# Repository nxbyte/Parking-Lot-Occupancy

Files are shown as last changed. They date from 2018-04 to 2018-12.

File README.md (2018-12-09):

# Parking Lot Occupancy

Undergraduate Senior Project focusing on detecting vehicle occupancy for parking lots



## Abstract

As The College of New Jersey increases its student and faculty size, there is an ever increasing need to manage its growth appropriately. One area in particular need of attention is parking on campus. Currently, many commuting facility, staff, and students attempt to find available parking spaces by driving around to different parking lots and guessing where parking spaces may be available.

The **Parking Lot Availability and Traffic Prediction System** provides commuters with information about the availability of free parking spaces, which will not only alleviate traffic congestion but also increase coordination for commuters. This system is made up of three components: detection nodes to detect vehicles entering and exiting parking lots, a base station that will host a wireless network to collect traffic data from each detection node, and a web server to provide current parking space availability at a glance. Each detection unit contains: sensors, wireless radio, and custom solar charging circuit for renewable outdoor operation. The base station contains a microcomputer and a wireless radio to communicate with each detection unit. All traffic data is securely stored and displayed on an Amazon web server which is accessible to TCNJ commuters. The final product allows commuters to view the status of open spaces and make The College of New Jersey a better and more coordinated campus. This system can be adapted to any environment with a gate and/or a road.

## Overall Architecture

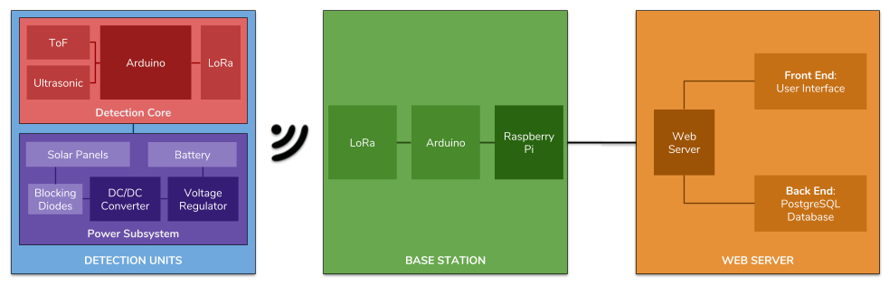
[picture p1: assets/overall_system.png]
Overall Architecture


## Credits

**Core Team**

- Warren Seto (Computer Engineer, Class of 2018)
- Nikita Eisenhauer (Electrical Engineer, Class of 2018)
- Stephanie Fournier (Electrical Engineer, Class of 2018)
- Matthew Cook (Computer Engineer, Class of 2018)
- Dr. Larry Pearlstein (Advisor)

**With help from...**

- Michael Steeil (TCNJ Engineering Laboratory Technician)
- Grant Cignarella (Mechanical Engineer, Class of 2020)
- Joshua Acker (Mechanical Engineer, Class of 2018)
- Lindsey Abramson (Computer Science, Class of 2018)
- Elisa Idrobo (Computer Science, Class of 2018)
- Philip Franco (Electrical Engineer, Class of 2019)
- Justin Cheng (Mechanical Engineer, Class of 2017)

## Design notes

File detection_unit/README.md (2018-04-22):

# Detection Unit

The Detection Unit is a device that is placed at the entrance and exit to each of the parking lots that are to be monitored with the system. 

**Each Detection Unit includes the following:**

- Microcontroller and sensor package, called Detection Unit Core
- Power subsystem, which includes solar panels, battery and associated electronics
- A 3D printed enclosure

## Microcontrollers

##### Adafruit Feather 32u4
The Adafruit Feather 32u4 microcontroller is an Arduino based microcontroller. The sensor has an onboard LoRa radio. The microcontroller uses SPI to communicate with the LoRa radio. The 32u4 also features an I2C interface, many different pins for GPIO, Digital IO, Analog IO, an antenna pin, a power cable connector for connecting to a power source, and a micro-USB port for power and programming.

##### Custom Arduino Microcontroller
The idea to make a PCB of an Arduino Uno was proposed to save cost, have experience with PCB CAD, and conserve space in the enclosure. The program used to design the PCB is Eagle CAD due to its compatibility with printing companies and its popularity allowing the user to have access to many tutorials. In order to build the Arduino, it is necessary to know the components used in an Arduino that will be needed in the PCB and all the hardware that will be needing the Arduino.

## Sensors & Peripherals

##### Ultrasonic Sensor
The Maxbotix LV-MaxSonar-EZ1 Ultrasonic Range Finder is an ultrasonic sensor that uses Analog output to communicate with a host microcontroller. Ultrasonic sensors emit ultrasonic pulses that can bounce off objects and calculate the distance based on the amount of time sound takes to reach the sensor. The sensor has a theoretical detection range of 6.45 meters from is initial position. Each Detection Unit Core uses one of these sensors positioned towards the curb of a street. The Ultrasonic Range Finder is used to detect whether a vehicle is passing by the Detection Unit.

##### Time of Flight Infrared Sensor
The Adafruit VL53L0X Time of Flight Distance Sensor is a LIDAR sensor that uses I2C to communicate with a host microcontroller. LIDAR is a technology that uses laser light pulses to determine the distance between the sensor and the object in front of the sensor. The sensor has a theoretical detection range of up to one meter from is initial position. Each Detection Unit Core uses one of these sensors positioned upwards the gate above the Detection Unit. The Time of Flight Sensor is used to detect the position of the gate and verify that an authorized vehicle has passed through the entrance of a parking lot. 

## Detection Algorithm

To accurately detect a vehicle, the group wanted to use all current infrastructure already setup in the parking lot such as the limited roadways and established gate units at the entrance. After researching into possible sensors to sense the state of the entrance, the group chose two types of sensors to go into each Detection Unit. The first sensor, the Maxbotix LV-MaxSonar-EZ1 Ultrasonic Range Finder, is tasked with detecting whether an entity (vehicle or animal) enters the parking lot. The Ultrasonic Range Finder, has a theoretical detection range of 6.45 meters (645 cm). After testing the sensor in the field, the sensor actually had a detection range of 4.5 meters (450 cm) which still satisfied the group’s detection requirements of detecting an entity on a 325 cm roadway. The first sensor, the Adafruit VL53L0X Time of Flight Distance Sensor, is tasked with detecting whether a given object entering the lot is authorized to enter by determining the position of the gate unit. The group determined that an authorized vehicle would make the gate rise which would be detected by the Distance sensor. The Time of Flight Distance Sensor, has a theoretical detection range of two meters (200 cm). After testing the sensor in the field, the sensor was tuned and scaled to sense a meter which satisfied the group’s detection requirements of detecting the gate at rest which was 92 cm above the island. Before any hardware was used for detection, the group calibrated each sensor with the gate and roadway in the entrance of the parking lot.

Through testing with driving vehicles through the entrance of the parking lot multiple times, the group determined that the Detection Unit will count an object as a valid vehicle entering the parking lot when both sensors reach a certain state. When the entrance to a parking lot has no vehicles entering, the ultrasonic sensor would read the maximum range value (approximately 450 cm) and the infrared distance sensor would read a constant 92 cm. When a vehicle enters the parking lot, the ultrasonic sensor would detect a drop in distance over a period of 4 seconds which will cause the infrared distance sensor to begin tracking the position of the gate unit for 5 seconds. Since the gate unit is near the maximum range of the distance sensor, when the gate unit opens the distance sensor will output the maximum range (2 meters). When both the ultrasonic sensor reads a drop in distance and the infrared distance sensor outputs its maximum range value, a vehicle is counted and sent to a centralized server. After performing various experiments with 100 entering vehicles, the group found that this method allowed the Detection Unit to detect 98% of authorized vehicles entering the parking lot. 

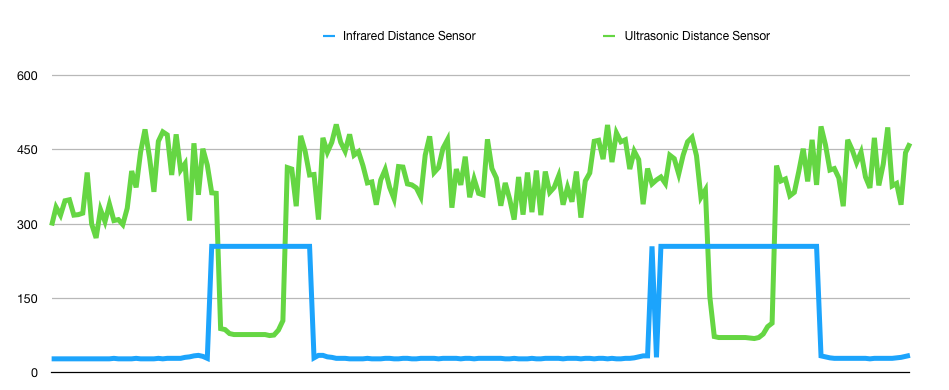
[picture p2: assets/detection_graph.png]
Sensor Graph


## Power Subsystem

Large pre-existing parking lots offer limited external power connections AC power, and the addition of such connections would be costly. Laying wires would present safety concerns for drivers and cumbersome gantry supports to allow overhead connections would be impractical. To minimize the burden of deployment of detection units in a large number of parking lots at TCNJ, we provide autonomous power to each detection unit, without requiring a connection to an AC power line. Stable, continuous power is required for proper operation of the detection unit subsystems and components.  A compact and standalone solar system was developed for use with each unit, allowing for greater freedom of placement and minimal external wiring as compared to alternative energy sources such as wind. Solar also provided scalable power as opposed to a much more restricted low power energy harvesting system. Charge storage in the event of poor solar insolation due to bad weather and for overnight detection unit power demands was accounted for with a LiPo battery charging circuit. LiPo batteries being available in significantly smaller packages than their Lithium-Ion battery counterparts allowed for the design of a smaller waterproof enclosure. To ensure battery longevity and safety, circuit elements to provide overcurrent and voltage regulation protection were included. Additionally, a DC/DC boost converter was necessary to account for the unique power demands and losses of the individual detection unit components. 

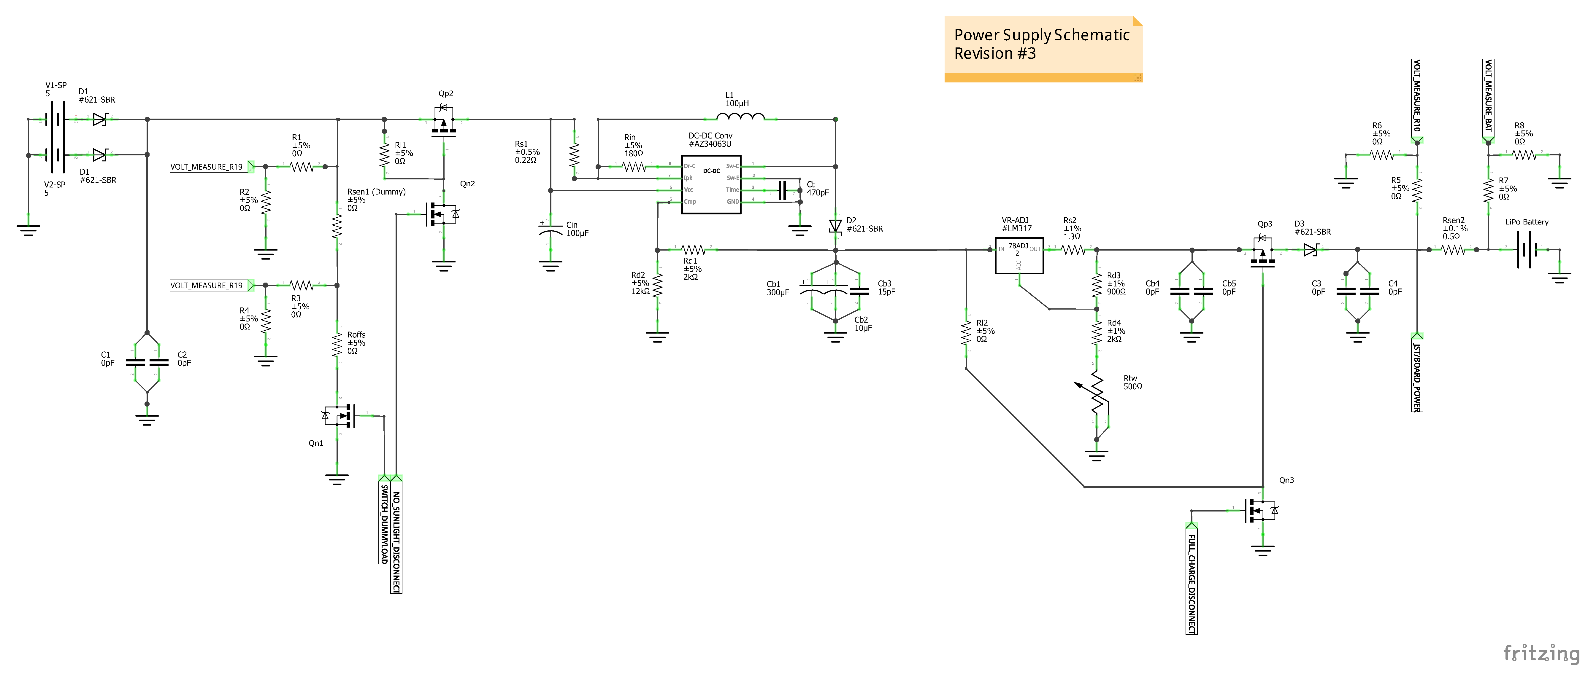
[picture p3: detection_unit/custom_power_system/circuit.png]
Overall Architecture


## Enclosure

A major component of this project is the detection system that relays the information of the sensors to the base station and the power system that powers the detection system using a solar panel. In order to keep all the components of each system in place and intact, an enclosure for the detection unit was proposed. Along with verifying that the hardware of these systems would be secure from the environment, it acts as a mount for the sensors to detect the moving vehicles. The design of the enclosure was based on the needs previously mentioned above and due to trial error, there are five versions of the first prototype all designed using CAD in Autodesk Fusion 360.

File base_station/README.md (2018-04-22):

# Base Station

The base station is a device that will receive payloads from the detection units and transmit its state to an Amazon cloud server. In order to receive payloads from the detection units, the base station will host a long distance wireless network with a designed range of one mile in diameter. Once a payload is received from a detection unit, the base station will decrypt the incoming transmission and parse the payload for metadata related to the detection unit that sent the data. Detection Unit payloads consists of: the client serial identification code and the payload to transmit to the Amazon cloud server. After decryption and parsing the payload, the base station will transmit the payload to the Amazon cloud server for further analysis. 

## Hardware

The hardware for the base station was chosen based on power usage, wireless performance, processing performance, and cost. The wireless network uses SemTech’s wireless LoRa (Long Range) technology. LoRa provides a greater wireless range than Wi-Fi, Bluetooth, or ZigBee while being more cost efficient than using a cellular network service as it does not incur wireless usage fees during its operation. The hosted wireless LoRa network will use the open 915 MHz ISM Band for ITU “Americas” which is free to use for industrial and scientific purposes. This allows the group to use publicly available spectrum space to transmit data on campus. The base station will have an antenna which is connected to an Arduino compatible Adafruit Feather that has the LoRa radio hardware for incoming transmissions. The Adafruit Feather connects to a 900 MHz dipole antenna to increase the range of the wireless network to encompass the TCNJ campus. The Adafruit Feather is then connected to a microcomputer called the Raspberry Pi to perform the routing and multiplexing needed to communicate with the Amazon cloud server. The Raspberry Pi features: USB to connect the Adafruit Feather to the microcomputer, 100-BaseT ethernet, and SD Card storage to hold the firmware that can be updated from a software update hosted from GitHub and the Amazon cloud server. The Raspberry Pi will be connected to the campus internet via CAT 6 Ethernet and a micro-USB 2 cable to power both the Raspberry Pi and the Adafruit Feather.

## Software

Based on the base station’s hardware, its software will need to provide routing functionality in between different system components. The Adafruit Feather with the LoRa radio will contain software will not only broadcast a LoRa wireless network using the 915 MHz spectrum space but also receive data that are transmitted from each detection unit. The Arduino software will be linked against the Arduino standard library and the RadioHead LoRa wireless library. The software on the Raspberry Pi will include a stripped-down Linux Debian operating system, the nodeJS server environment, and controller code to accept serial data from the Adafruit Feather and multiplex the payload to the Amazon cloud server. On boot, the Raspberry Pi will attempt to search for and update itself with the latest software from GitHub. Then the nodeJS server will then route the received payload.

## Enclosure

The team also designed an enclosure to house the components that will be needed for the base station. The base station will be located within the interior of the building and does not need to be weatherproof. This allowed the design to be more flexible in terms of its open holes and places where there needs to be sealed. To house the components, there is a top and bottom which allows the components to be mounted on the bottom and a twist on lid to completely enclosure the components. Holes and grooves on the bottom will allow for cable routing for power, ethernet and USB.

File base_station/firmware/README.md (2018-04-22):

# R1
Repository for Internal Wireless Router assets

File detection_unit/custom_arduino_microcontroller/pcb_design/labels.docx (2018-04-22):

LoRa - 9 hole header

9 - RST

8 - CS

7 - MOSI

6 - MISO

5 - SCK

4 - G0

3 - EN

2 - GND

1 - VIN

LIDAR - 14 hole header, each column representing one sensor

13, 14 - Vin

11, 12 - 2v8

9, 10 - GND

7, 8 - GPIO

5, 6 - SHDN

3, 4 - SCL

1, 2 - SDA

ATMEGA328P-PU - 30 hole header (didn’t have a 28 header). Each column representing one side of the chip.

27 - PC6 28 - PC5

25 - PD0 26 - PC4

23 - PD1 24 - PC3

21 - PD2 22 - PC2

19 - PD3 20 - PC1

17 - PD4 18 - PC0

15 - VCC 16 - GND

13 - GND 14 - AREF

11 - PB6 12 - AVCC

9 - PB7 10 - PB5

7 - PD5 8 - PB4

5 - PD6 6 - PB3

3 - PD7 4 - PB2

1 - PB0 2 - PB1

FTDI

6 - PC6 (1)

5 - PD1 (3)

4 - PD0 (2)

3 - VCC (7)

2 -

1 - GND (8)

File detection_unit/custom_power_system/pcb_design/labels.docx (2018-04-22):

3 pin header:

1 - “dummy load switch”

2 - “primary no sunlight”

3 - “secondary no sunlight”

4 pin header:

1 - “dummy load top”

2 - “dummy load bottom”

3 - “battery left”

4 - “battery right”

7 pin header:

1 - “solar panel 1”

2 - “solar panel 2”

3 - Battery

4 - Load

5 - GND

6 - GND

7 - GND

Q1 - leftmost diode on schematic

Q2 - middle diode on schematic

Q3 - rightmost diode on schematic

JP1: diode after solar panel test point

JP2: between resistors near Q5

JP3: pinout 6 on DC/DC

JP4: pinout 1/ between diode and inductor

JP5: VIN regulator

JP6: VOUT regulator

JP7: Potentiometer

JP8: battery

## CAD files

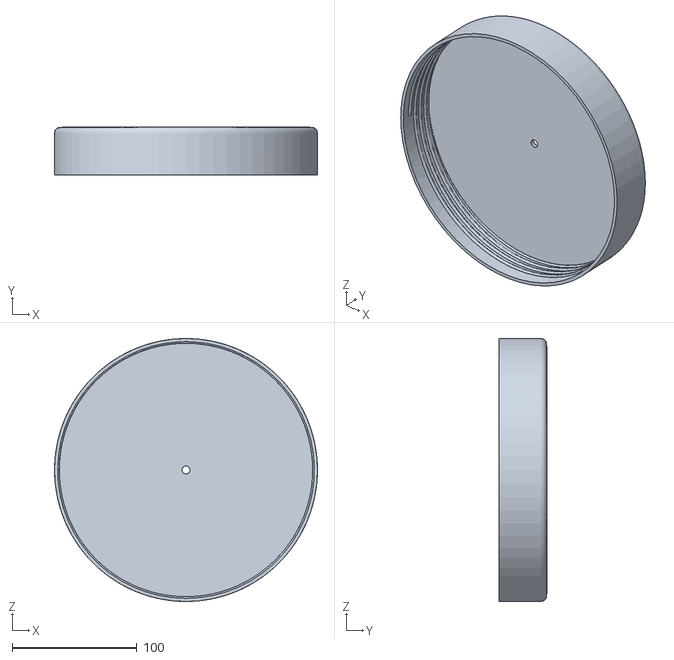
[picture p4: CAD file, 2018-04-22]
base_station/enclosure/lid.stl
210.8 x 38.1 x 210.8

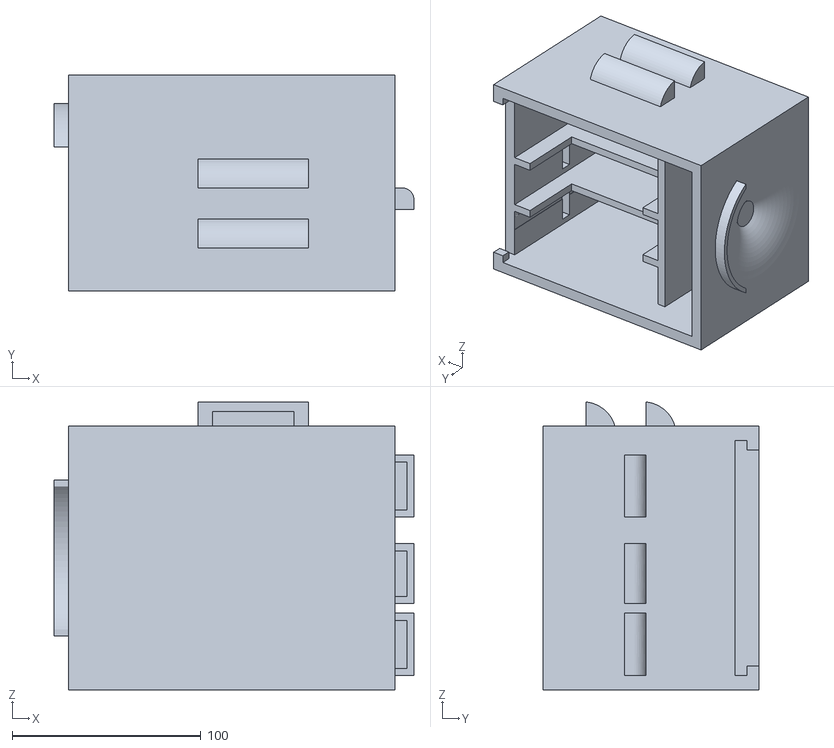
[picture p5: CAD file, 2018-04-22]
detection_unit/enclosure/body.stl
190.5 x 114.3 x 152.4

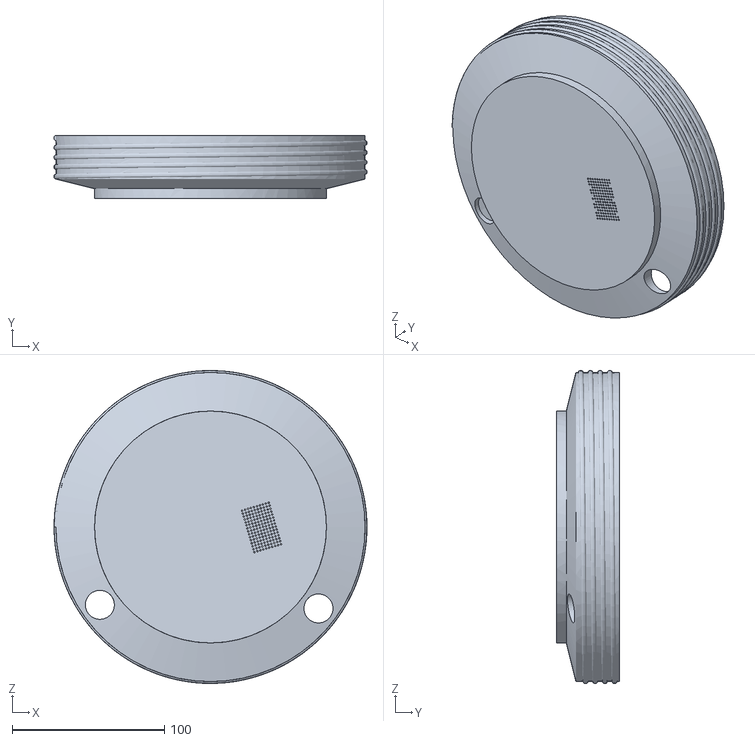
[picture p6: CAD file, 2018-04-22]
base_station/enclosure/body.stl
205.7 x 41.3 x 205.7

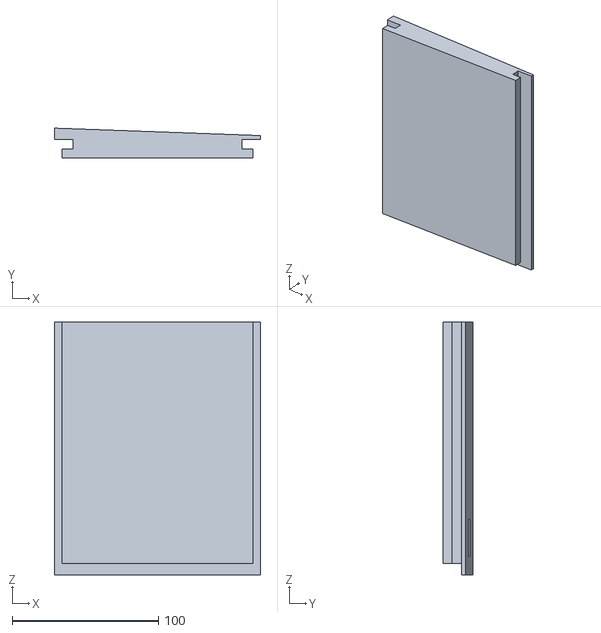
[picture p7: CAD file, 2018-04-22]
detection_unit/enclosure/lid.stl
141.0 x 20.3 x 172.7

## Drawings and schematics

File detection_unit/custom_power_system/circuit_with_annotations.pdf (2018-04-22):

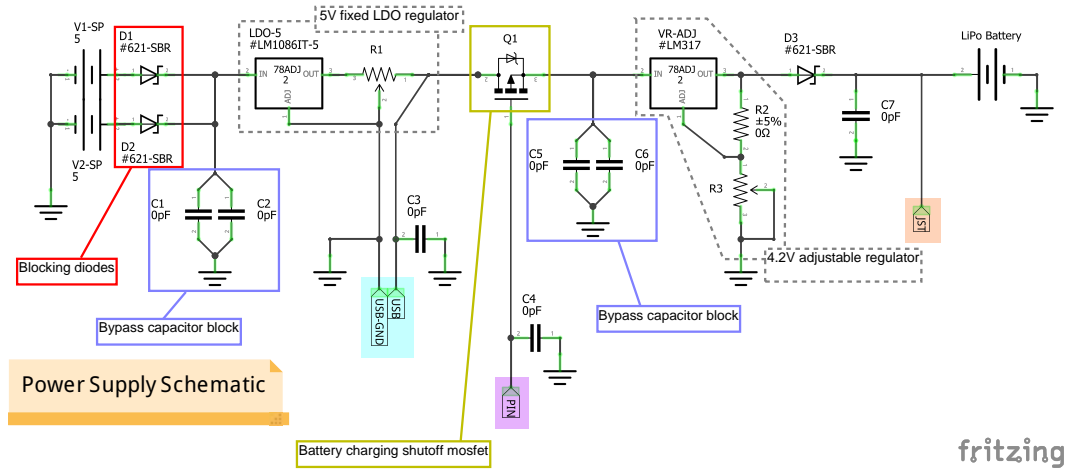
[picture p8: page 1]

Power Supply Schematic

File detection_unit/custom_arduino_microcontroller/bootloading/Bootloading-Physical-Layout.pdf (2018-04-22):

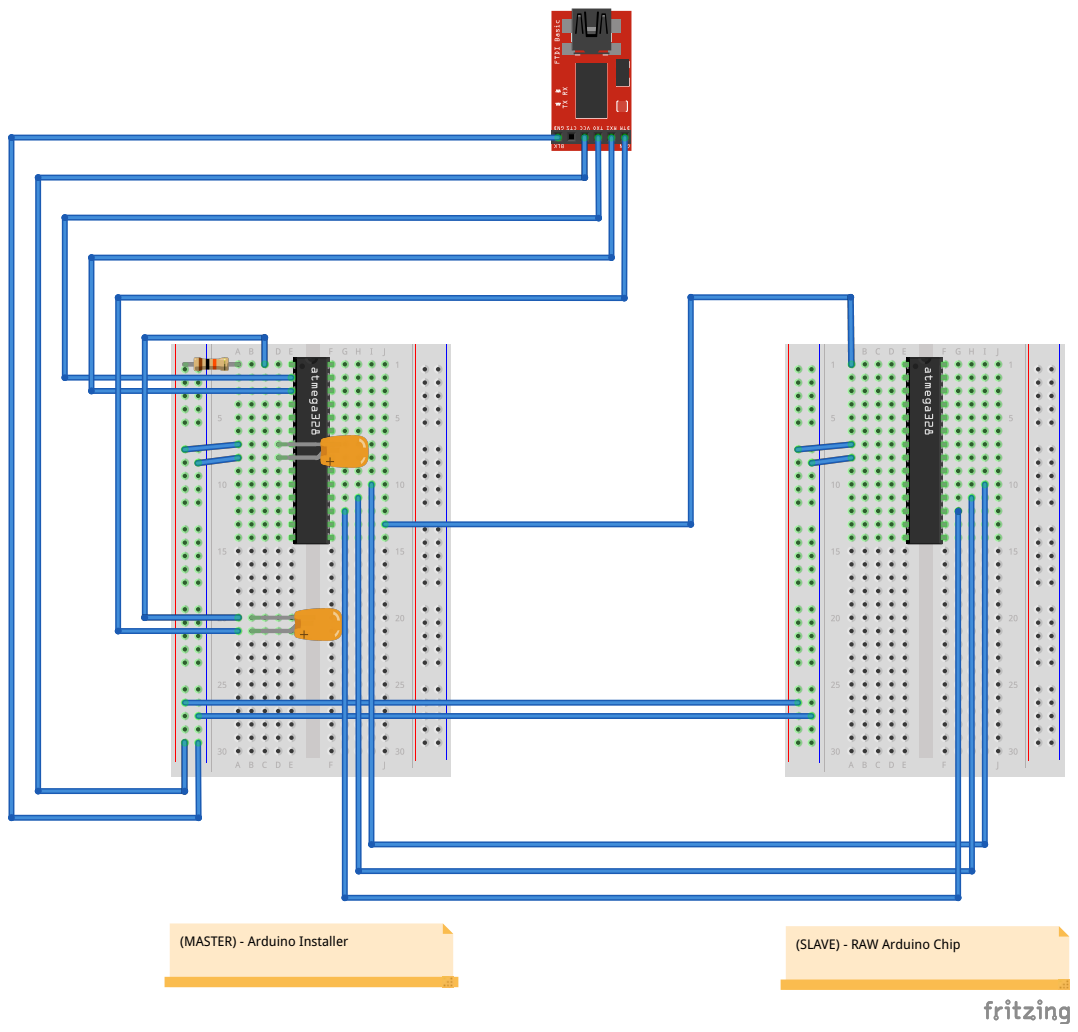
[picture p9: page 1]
(MASTER) - Arduino Installer; (SLAVE) - RAW Arduino Chip

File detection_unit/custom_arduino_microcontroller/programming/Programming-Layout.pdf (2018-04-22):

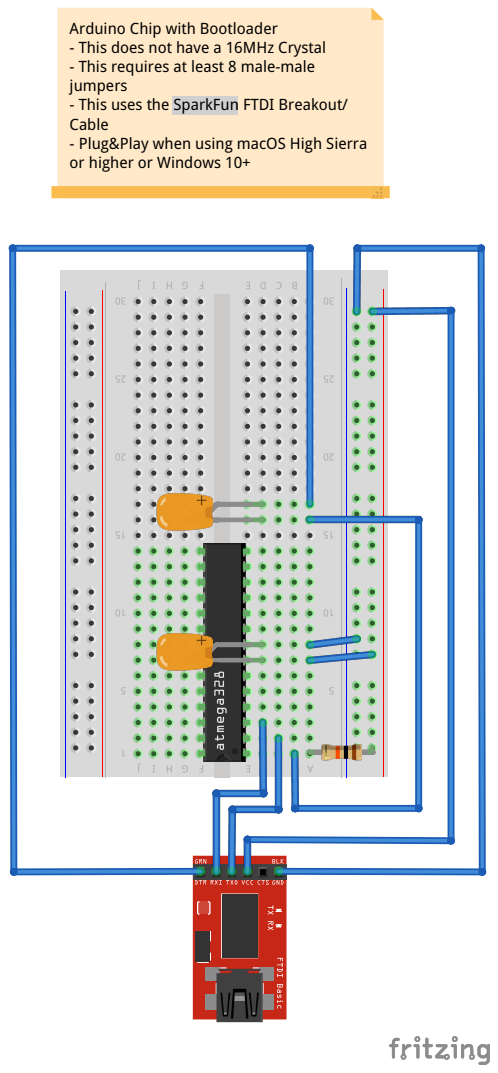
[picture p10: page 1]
the SparkFun

Arduino Chip with Bootloader
- This does not have a 16MHz Crystal
- This requires at least 8 male-male
jumpers

Cable
- Plug&Play when using macOS High Sierra
or higher or Windows 10+

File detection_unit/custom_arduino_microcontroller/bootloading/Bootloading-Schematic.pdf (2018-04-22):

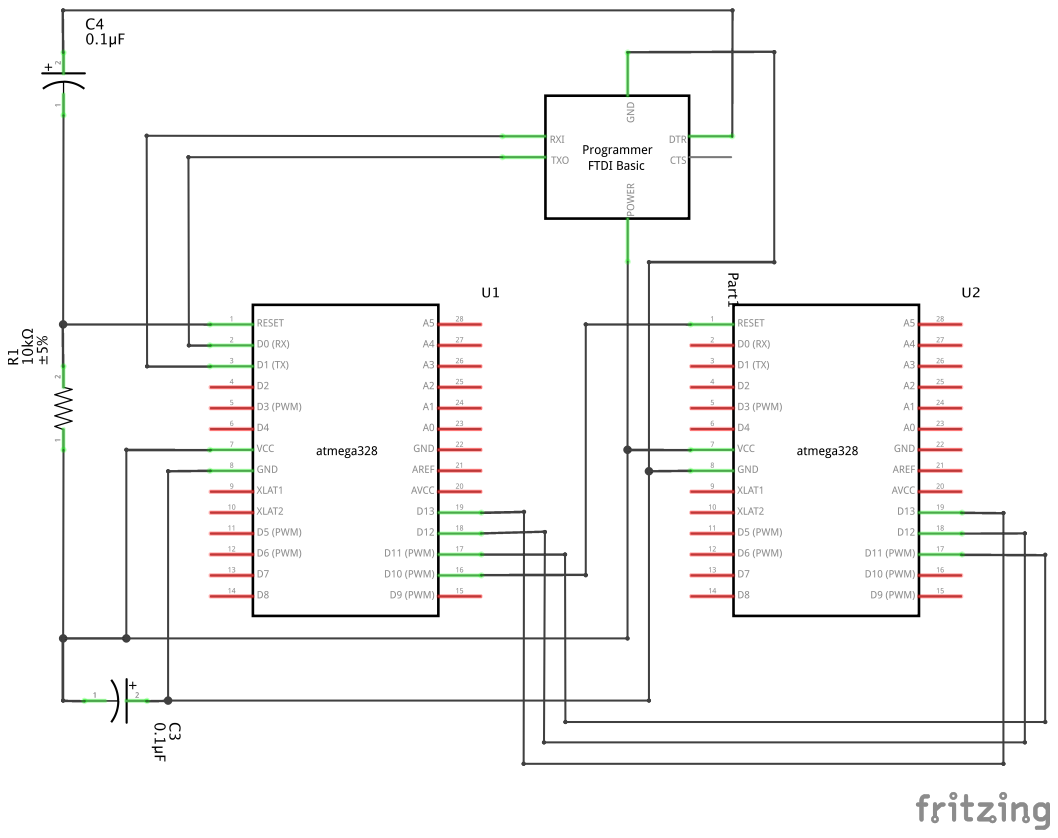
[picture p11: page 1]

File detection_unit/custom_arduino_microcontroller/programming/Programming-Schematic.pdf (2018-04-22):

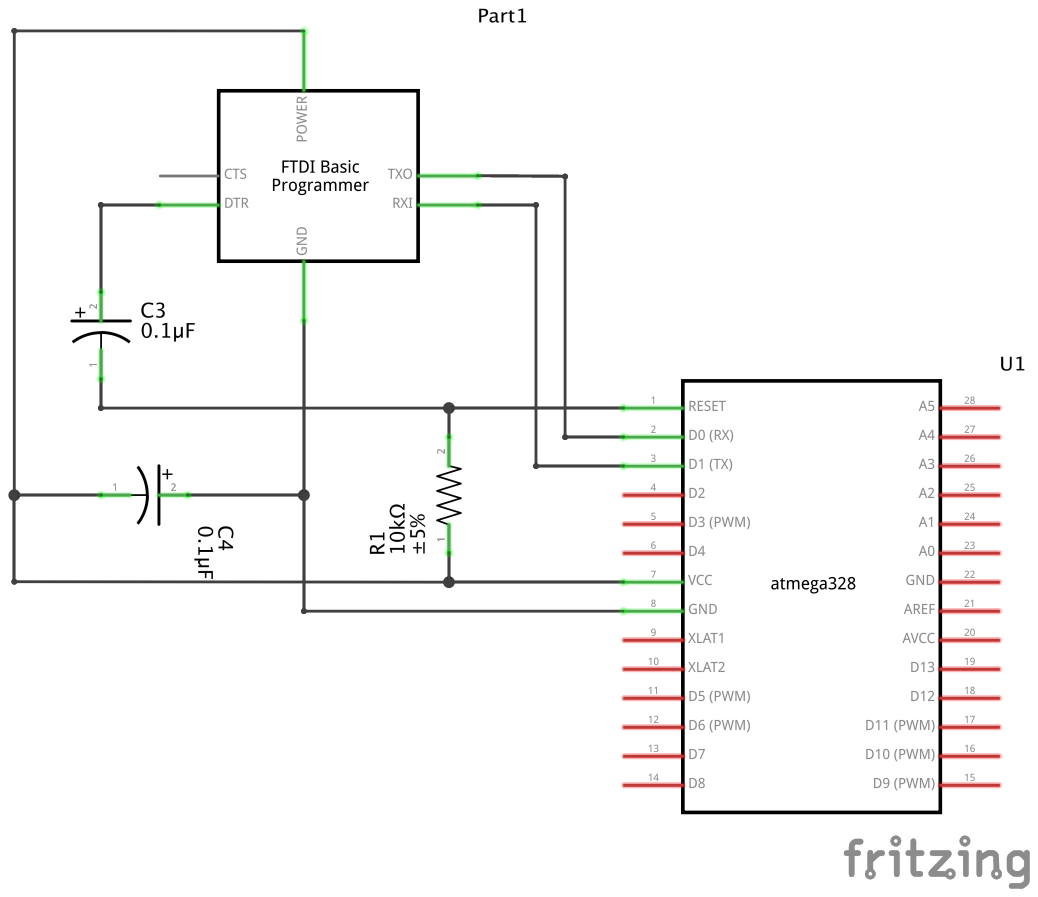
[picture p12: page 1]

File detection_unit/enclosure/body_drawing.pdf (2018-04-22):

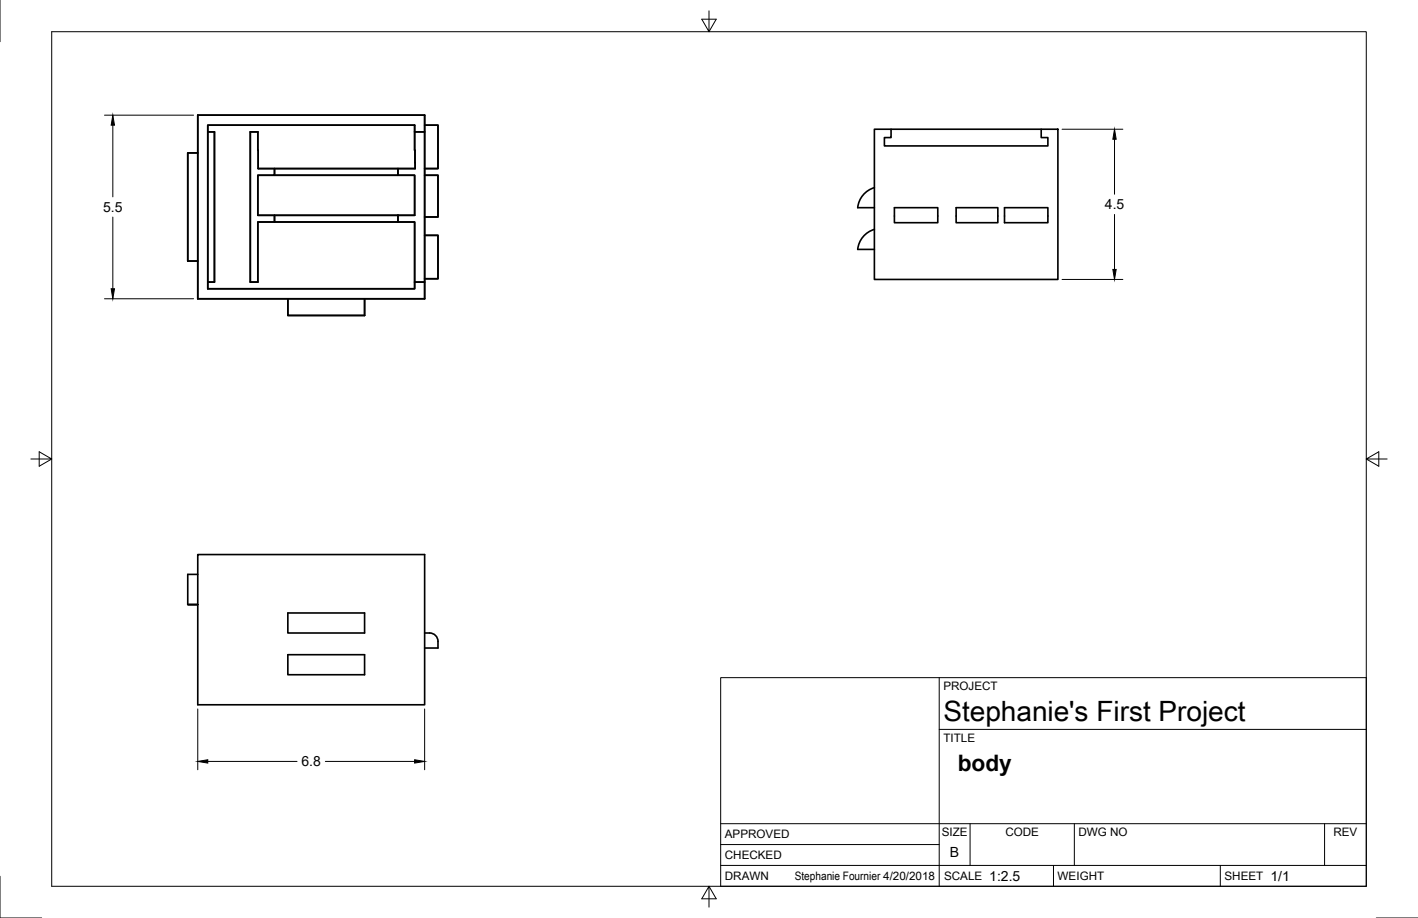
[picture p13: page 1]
SIZE; CODE; DWG NO; REV; Stephanie Fournier 4/20/2018; Stephanie's First Project; n1final v4

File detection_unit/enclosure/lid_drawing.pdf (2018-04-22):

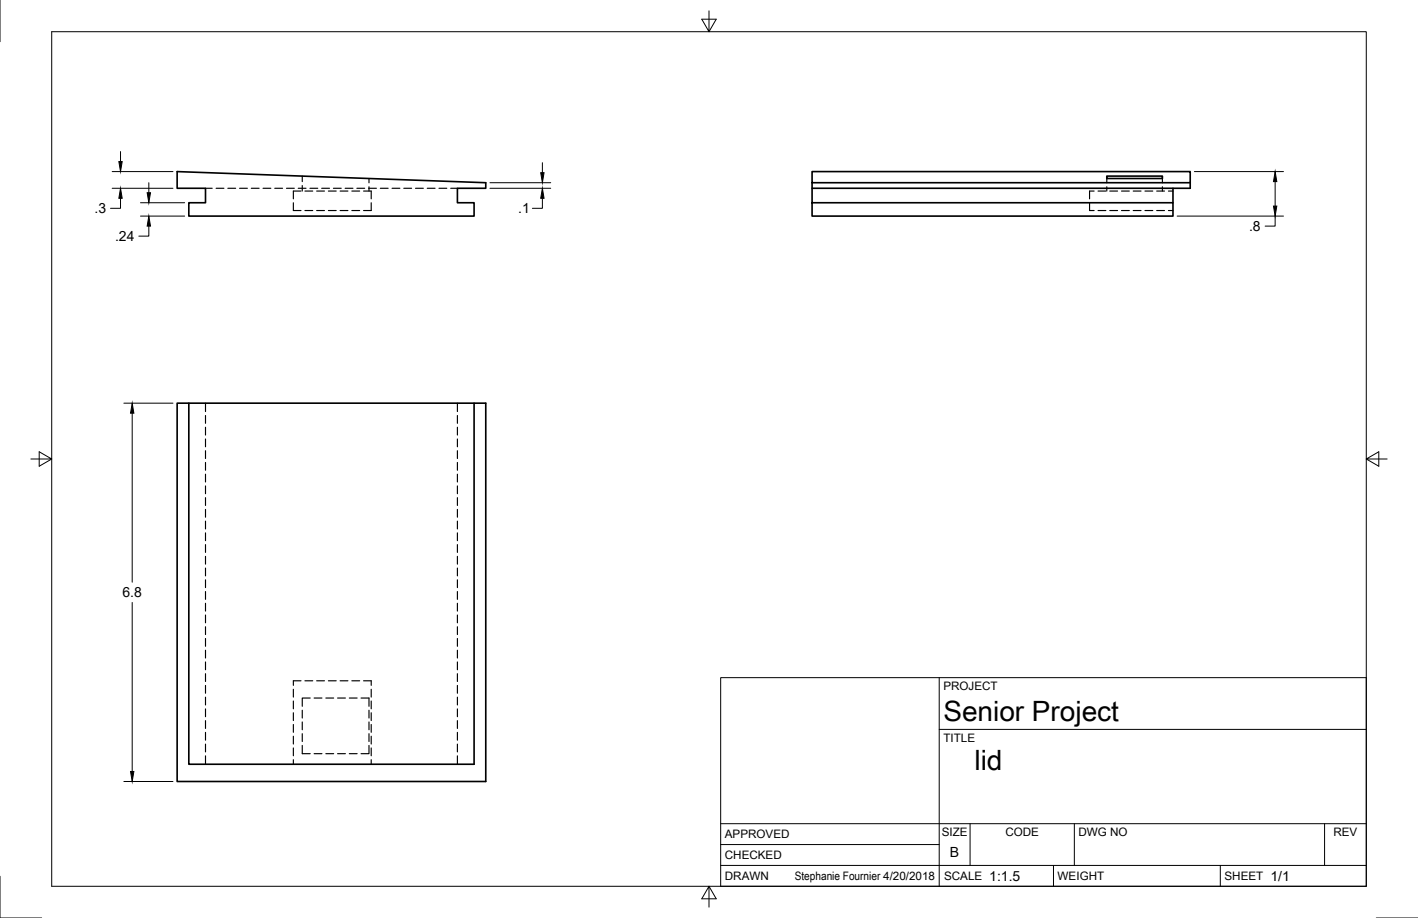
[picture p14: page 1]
SIZE; CODE; DWG NO; REV; Stephanie Fournier 4/20/2018; Senior Project

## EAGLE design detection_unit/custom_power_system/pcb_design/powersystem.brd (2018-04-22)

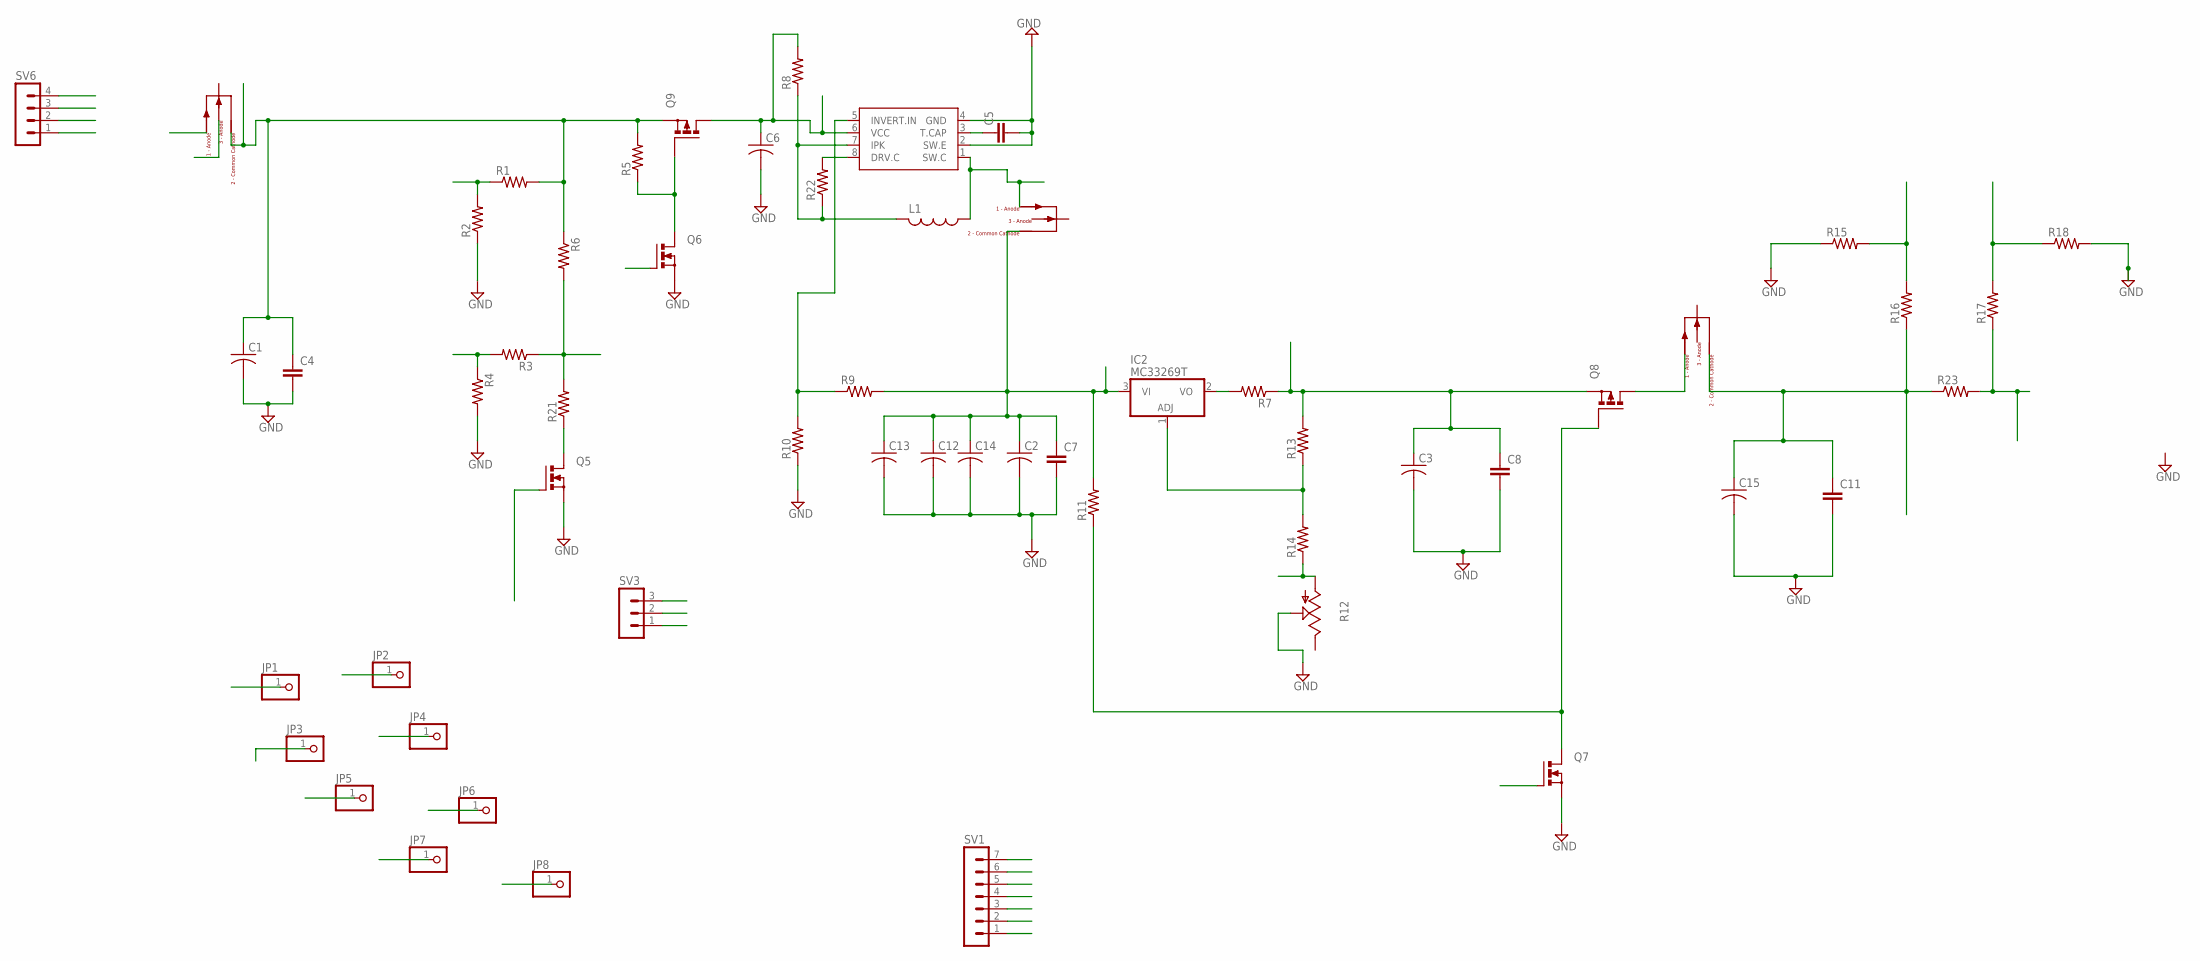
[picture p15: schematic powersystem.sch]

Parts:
C1, C2, C3, C6, C12, C13, C14, C15: C-US025-024X044; C025-024X044
C4, C5, C7, C8, C11: C2.5/2; C2.5-2
IC2: MC33269T; TO220V
JP1, JP2, JP3, JP4, JP5, JP6, JP7, JP8: PINHD-1X1; 1X01
L1: L-US0204/5; 0204/5
Q1, Q2, Q3: PMOSFET_N; TO220BV
Q4: UCC38050; DIP-8
Q5, Q6, Q7: PMOSFET_NTO220BV; TO220BV
Q8, Q9: PMOSFET_PTO220BV; TO220BV
R1, R2, R3, R4, R5, R6, R9, R10, R11, R13, R14, R15, R16, R17, R18, R21: R-US_0204/7; 0204/7
R7, R8, R22, R23: R-US_0207/10; 0207/10
R12: TRIM_US-CA6H; CA6H
SV1: MA07-1
SV3: MA03-1
SV6: MA04-1

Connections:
BATTERY: JP8.1, R17.1, R23.2, SV1.3
BATTERYLEFT: R15.2, R16.2, SV6.3
BATTERYRIGHT: R17.2, R18.1, SV6.4
BETWEENRESISTOR: JP2.1, R3.1, R6.2, R21.2
DIODE1: C1.1, C4.1, JP1.1, Q1.D, Q9.S, R1.2, R5.2, R6.1
DUMMYLOADBOTTOM: R3.2, R4.1, SV6.2
DUMMYLOADSWITCH: Q5.G, SV3.1
DUMMYLOADTOP: R1.1, R2.2, SV6.1
GND: C1.2, C2.2, C3.2, C4.2, C5.2, C6.2, C7.2, C8.2, C11.2, C12.2, C13.2, C14.2, C15.2, Q4.2 (SW.E), Q4.4 (GND), Q5.S, Q6.S, Q7.S, R2.1, R4.2, R10.1, R12.S, R15.1, R18.2, SV1.5, SV1.6, SV1.7
LOAD: C11.1, C15.1, Q3.D, R16.1, R23.1, SV1.4
unnamed: Q6.D, Q9.G, R5.1
unnamed: Q4.5 (INVERT.IN), R9.1, R10.2
unnamed: Q4.8 (DRV.C), R22.2
unnamed: Q7.D, Q8.G, R11.1
unnamed: IC2.1 (ADJ), R13.1, R14.2
unnamed: Q3.S, Q8.D
unnamed: Q5.D, R21.1
unnamed: IC2.2 (VO), R7.2
unnamed: L1.2, Q4.7 (IPK), R8.1, R22.1
unnamed: C5.1, Q4.3 (T.CAP)
PINOUT1: JP4.1, L1.1, Q2.S, Q4.1 (SW.C)
PINOUT6: C6.1, JP3.1, Q4.6 (VCC), Q9.D, R8.2
POT: JP7.1, R12.A, R14.1
PRIMARYNOSUNLIGHT: Q6.G, SV3.2
SECONDARYNOSUNLIGHT: Q7.G, SV3.3
SOLARPANEL1: Q1.S, SV1.1
SOLARPANEL2: Q1.G, SV1.2
VINREG: C2.1, C7.1, C12.1, C13.1, C14.1, IC2.3 (VI), JP5.1, Q2.D, R9.2, R11.2
VOUTREG: C3.1, C8.1, JP6.1, Q8.S, R7.1, R13.2

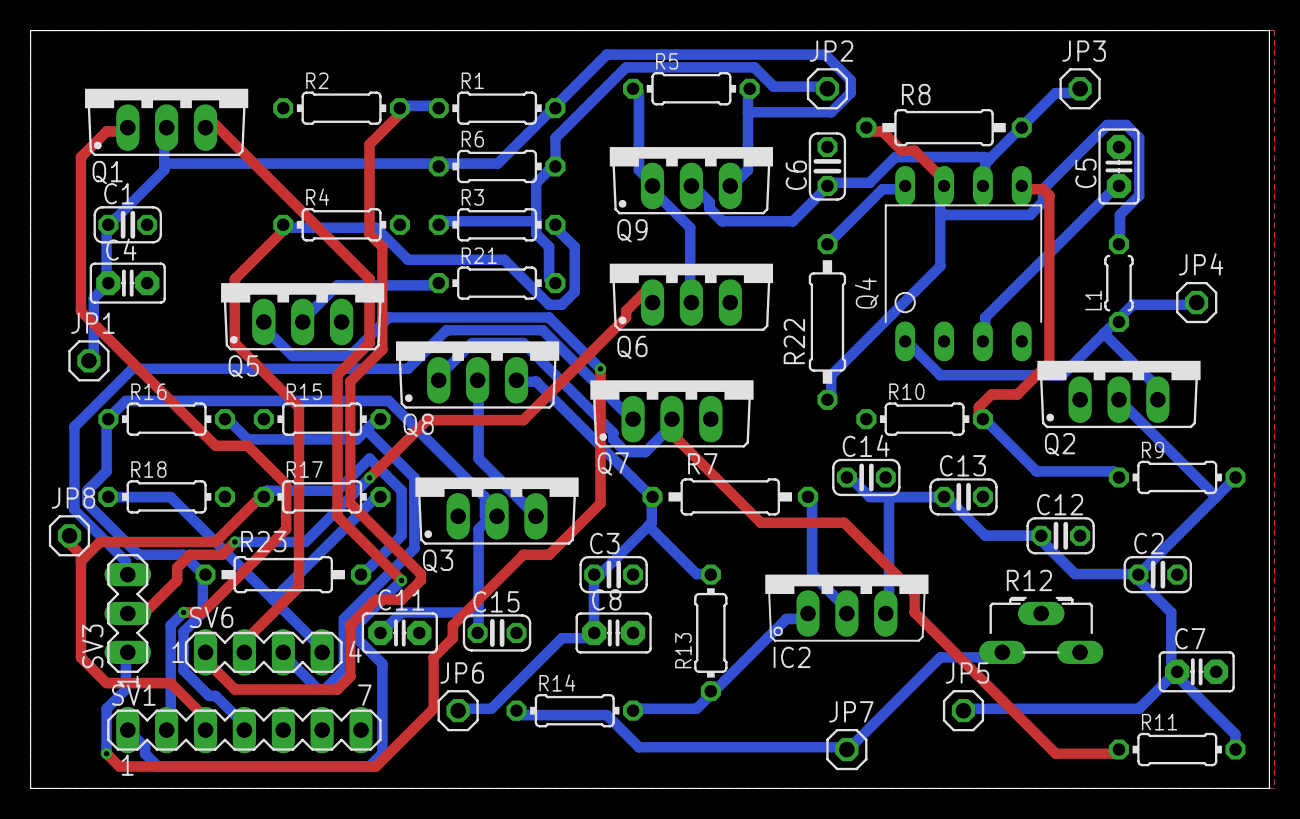
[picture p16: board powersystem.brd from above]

Board: 2 copper layers, 81.0 x 49.5 mm, 56 parts (0 on the bottom side), 29 nets.

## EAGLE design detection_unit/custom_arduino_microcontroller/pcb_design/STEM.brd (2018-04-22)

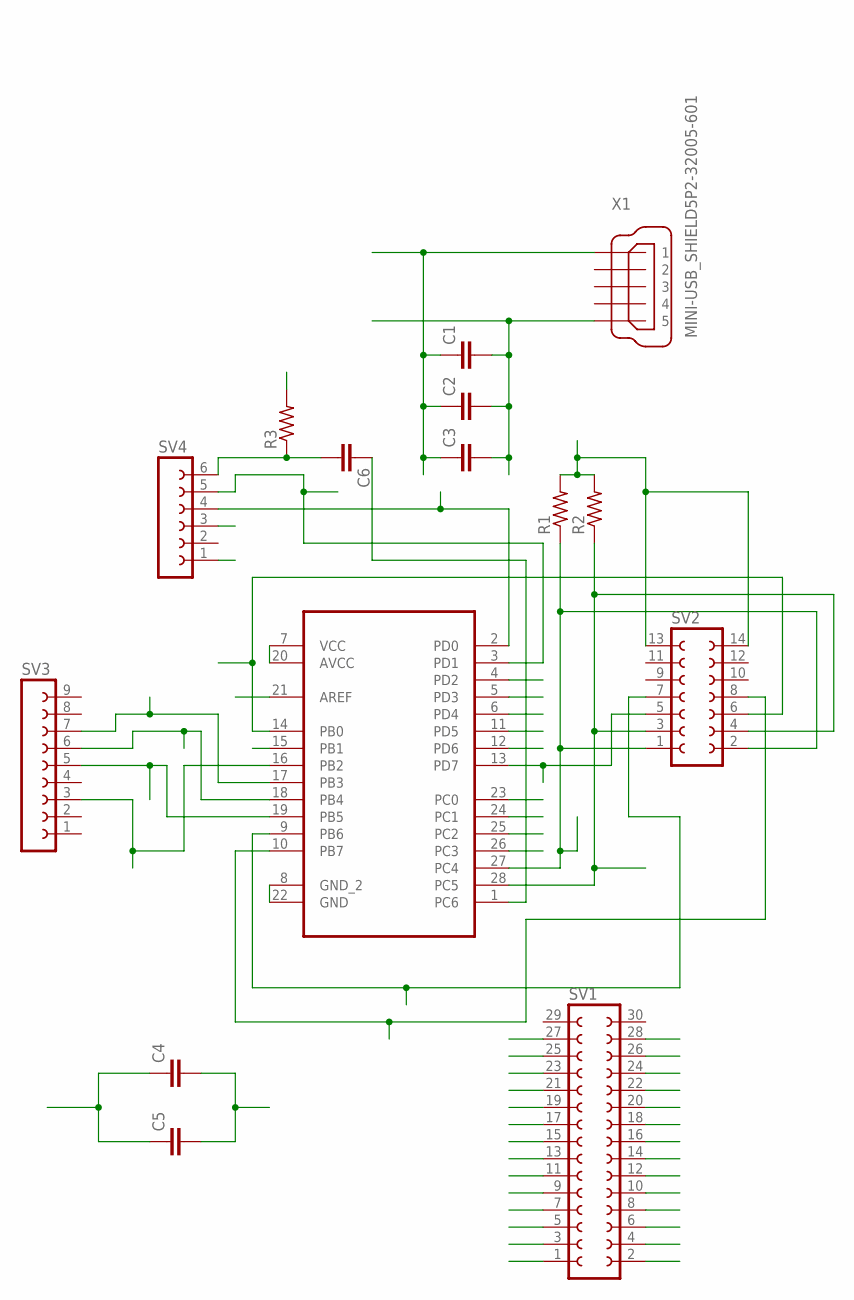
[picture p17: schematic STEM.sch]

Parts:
C1, C2, C3, C4, C5, C6: C2,5-3; C2.5-3
R1, R2, R3: R-US_0204/7; 0204/7
SV1: FE15-2
SV2: FE07-2
SV3: FE09-1; FE09
SV4: FE06-1; FE06
U1: ATMEGA328P-PU; DIP254P762X457-28
X1: MINI-USB_SHIELD5P2-32005-601; 32005-601

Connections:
AREF: C4.1, C5.1, SV1.14, U1.21 (AREF)
GND: C1.2, C2.2, C3.2, C4.2, C5.2, SV1.13, SV1.16, SV4.1, U1.8 (GND_2), U1.22 (GND), X1.5
PB0: SV1.1, SV2.6, U1.14 (PB0)
PB1: SV1.2, U1.15 (PB1)
PB2: SV1.4, SV3.3, U1.16 (PB2)
PB3: SV1.6, SV3.7, U1.17 (PB3)
PB4: SV1.8, SV3.6, U1.18 (PB4)
PB5: SV1.10, SV3.5, U1.19 (PB5)
PB6: SV1.11, SV2.7, U1.9 (PB6)
PB7: SV1.9, SV2.8, U1.10 (PB7)
PC0: SV1.18, U1.23 (PC0)
PC1: SV1.20, U1.24 (PC1)
PC2: SV1.22, U1.25 (PC2)
PC3: SV1.24, U1.26 (PC3)
PC4: R1.1, SV1.26, SV2.1, SV2.2, U1.27 (PC4)
PC5: R2.1, SV1.28, SV2.3, SV2.4, U1.28 (PC5)
PC6: C6.1, SV1.27, U1.1 (PC6)
PC62: C6.2, R3.1, SV4.6
PD0: SV1.25, SV4.4, U1.2 (PD0)
PD1: SV1.23, SV4.5, U1.3 (PD1)
PD2: SV1.21, U1.4 (PD2)
PD3: SV1.19, U1.5 (PD3)
PD4: SV1.17, U1.6 (PD4)
PD5: SV1.7, U1.11 (PD5)
PD6: SV1.5, U1.12 (PD6)
PD7: SV1.3, SV2.5, U1.13 (PD7)
VCC: C1.1, C2.1, C3.1, R1.2, R2.2, R3.2, SV1.12, SV1.15, SV2.13, SV2.14, SV4.3, U1.7 (VCC), U1.20 (AVCC), X1.1

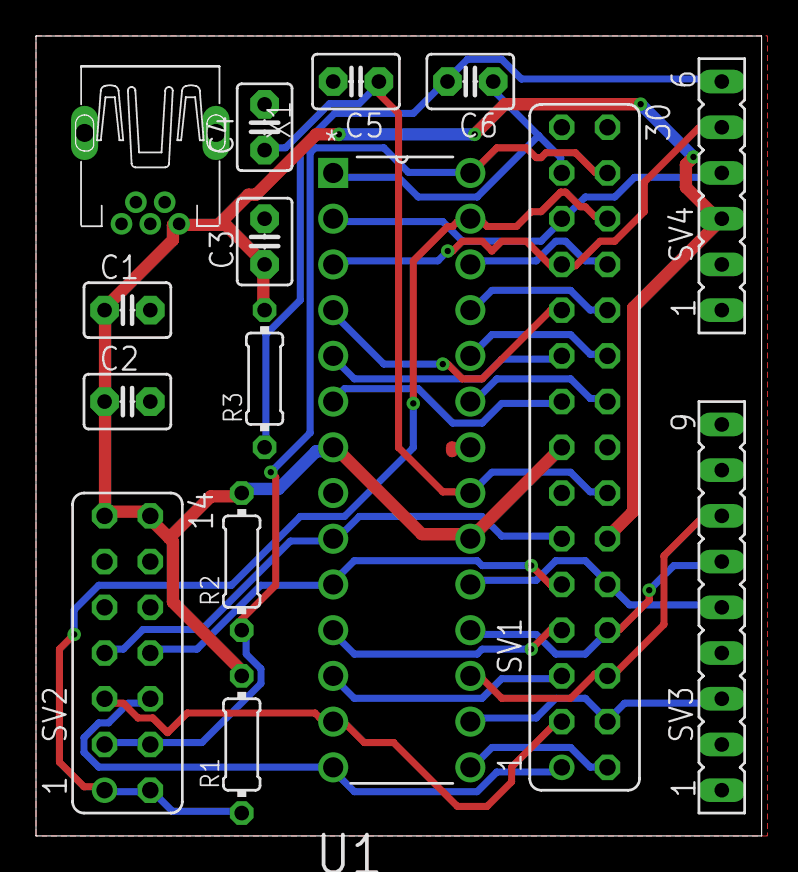
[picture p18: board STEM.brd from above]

Board: 2 copper layers, 40.3 x 44.4 mm, 15 parts (0 on the bottom side), 27 nets.

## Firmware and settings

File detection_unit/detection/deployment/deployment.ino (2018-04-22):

// Senior Project

#include <Wire.h>
#include <VL53L0X.h>
#include <LoRaNetwork.h>

#define SONIC_PIN A5
#define SONIC_THRESHOLD 0x9798999A              // Detect Car: Sensor detects 150 or lower (Car should be detected as passed by)
#define SONIC_TIMER_PRESCALER 0x3

#define INFRARED_THRESHOLD 0x2e2f3031           // Detect Car: Sensor detects 32 or greater (Gate up should read a buffer of 255)
#define INFRARED_TIMER 200
#define INFRARED_AMOUNT_SENSE 15

#define BATTERY_TIMER_PRESCALER 0x5

uint8_t car_count;                              // Variable to keep car count

volatile uint64_t ultrasonic_buffer;            // Buffer to hold previous ultrasonic readings

uint64_t infrared_buffer;                       // Buffer to hold previous time of flight readings
uint8_t infrared_counter;                       // Predefined counter for time of flight sensor analysis
VL53L0X infrared;                               // Object that configures time of flight sensor

Network wireless;                               // LoRa Network Driver


/* Setup Procedure : Setup sensors, initialize variables, and configures timers */
void setup()
{
  wireless.init();                              // Initialize Wireless Network Driver
  Serial.begin(9600);                           // Enable Serial Debugging
  pinMode(SONIC_PIN, INPUT);                    // Enable Reading Ultrasound Pin
  
  car_count = 0;                                // Initialize Car Counter

  ultrasonic_buffer = 0xFFFFFFFF;               // Initialize Ultrasound Buffer
  infrared_buffer = 0x00000000;                 // Initialize Infrared Buffer
  
  Wire.begin();                                 // Initialize Infrared I2C
  infrared.init(false);                         // Initialize Infrared Device
  infrared.setMeasurementTimingBudget(200000);  // Accurate measurement (200 ms)

  noInterrupts();                               // Disable All Interrupts for setting up timers
  
  /* Timer 1 Setup: Ultrasonic */
  TCNT1 = 0;                                    // Set Initial value
  TIMSK1 = 0x01;                                // Enable/Disable Timer1
  TCCR1A = 0;                                   // Disable PWM output pin
  TCCR1B = SONIC_TIMER_PRESCALER;               // Set Timer1 prescaler to 64

  /* Timer 3 Setup: Battery Readings */
  TCNT3 = 0;                                    // Set Initial value
  TIMSK3 = 0x01;                                // Enable/Disable Timer3
  TCCR3A = 0;                                   // Disable PWM output pin
  TCCR3B = BATTERY_TIMER_PRESCALER;             // Set Timer3 prescaler to 1024

  interrupts();                                 // Enable All Interrupts after setting up timers
}

/* Timer1 : Ultrasound sensing every 500 ms */
ISR(TIMER1_OVF_vect)
{
  Serial.println("ULTRA");
  ultrasonic_buffer <<= 8;                                // Shift values in the buffer to make room for a new uint8_t value
  ultrasonic_buffer += min(analogRead(SONIC_PIN), 0xFF);  // Add new uint8_t value into the buffer
}

/* Timer3 : Battery Reading every 8.4 seconds */
ISR(TIMER3_OVF_vect)
{
  Serial.println("BATTERY");
  // TODO
}

void loop()
{
    /*
    // Debug Ultrasound
    Serial.print("Uls:   ");
    Serial.print((unsigned long)ultrasonic_buffer, HEX);
    Serial.print(" ?<=? ");
    Serial.println((unsigned long)SONIC_THRESHOLD, HEX);
    */

  // Check the ultrasonic buffer to see if its senses something moving within a threshold  
  if ((unsigned long)ultrasonic_buffer <= SONIC_THRESHOLD) 
  {
    infrared_counter = INFRARED_AMOUNT_SENSE;
    
    infrared.startContinuous(INFRARED_TIMER);
 
    while(infrared_counter--) 
    {
      infrared_buffer <<= 8;
      infrared_buffer += (uint8_t)(infrared.readRangeContinuousMillimeters() / 32);
    }

    infrared.stopContinuous();

    /*
    // Debug ToF
    Serial.print("ToF:   ");
    Serial.print((unsigned long)infrared_buffer, HEX);
    Serial.print(" ?>? ");
    Serial.println((unsigned long)INFRARED_THRESHOLD, HEX);
    */
      
    if ((unsigned long)infrared_buffer > INFRARED_THRESHOLD) 
    {
      car_count++;
    }

    // Resets both buffers to sense another new vehicle  
    ultrasonic_buffer = 0xFFFFFFFF;
    infrared_buffer = 0x00000000;
  }
  else if (car_count > 0) 
  {
    wireless.send_count(car_count);
    
    Serial.print("TRANSMIT");
    Serial.println(car_count);
    
    car_count = 0;
  }
}

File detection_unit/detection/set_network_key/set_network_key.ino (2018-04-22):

/* 
 * Project : Senior Project
 * Purpose : Writes the NodeID for a specific device into a 32u4 microcontroller
 */

#include <EEPROM.h>

boolean eeprom_is_addr_ok(int addr);
boolean eeprom_write_bytes(int startAddr, const byte* array, int numBytes);
boolean eeprom_write_string(int addr, const char* string);
boolean eeprom_read_string(int addr, char* buffer, int bufSize);

#define NETWORK_KEY_SIZE 5
#define WRITE_BOOL false

char write_network_id[NETWORK_KEY_SIZE] = "CR4P";
char read_network_id[NETWORK_KEY_SIZE];

void setup()
{
  Serial.begin(9600);

  if (WRITE_BOOL) 
  {
    Serial.println("Saving string to address 0");
    eeprom_write_string(0, write_network_id);
  }
}

void loop() 
{
  Serial.print("EEPROM[0:4] = ");
  eeprom_read_string(0, read_network_id, NETWORK_KEY_SIZE);
  Serial.println(read_network_id);  
  delay(1000);
}


/* --- Complicated section below... --- */

// Absolute min and max eeprom addresses. Actual values are hardware-dependent.
// These values can be changed e.g. to protect eeprom cells outside this range.
#define EEPROM_MIN_ADDR 0
#define EEPROM_MAX_ADDR 1023

// Returns true if the address is between the
// minimum and maximum allowed values, false otherwise.
//
// This function is used by the other, higher-level functions
// to prevent bugs and runtime errors due to invalid addresses.
boolean eeprom_is_addr_ok(int addr) {
  return ((addr >= EEPROM_MIN_ADDR) && (addr <= EEPROM_MAX_ADDR));
}

// Writes a sequence of bytes to eeprom starting at the specified address.
// Returns true if the whole array is successfully written.
// Returns false if the start or end addresses aren't between
// the minimum and maximum allowed values.
// When returning false, nothing gets written to eeprom.
boolean eeprom_write_bytes(int startAddr, const byte* array, int numBytes) {
  // counter
  int i;
  // both first byte and last byte addresses must fall within
  // the allowed range
  if (!eeprom_is_addr_ok(startAddr) || !eeprom_is_addr_ok(startAddr + numBytes)) {
    return false;
  }
  for (i = 0; i < numBytes; i++) {
    EEPROM.write(startAddr + i, array[i]);
  }
  return true;
}

// Writes a string starting at the specified address.
// Returns true if the whole string is successfully written.
// Returns false if the address of one or more bytes fall outside the allowed range.
// If false is returned, nothing gets written to the eeprom.
boolean eeprom_write_string(int addr, const char* string) {

  int numBytes; // actual number of bytes to be written
  //write the string contents plus the string terminator byte (0x00)
  numBytes = strlen(string) + 1;
  return eeprom_write_bytes(addr, (const byte*)string, numBytes);
}

// Reads a string starting from the specified address.
// Returns true if at least one byte (even only the string terminator one) is read.
// Returns false if the start address falls outside the allowed range or declare buffer size is zero.
//
// The reading might stop for several reasons:
// - no more space in the provided buffer
// - last eeprom address reached
// - string terminator byte (0x00) encountered.
boolean eeprom_read_string(int addr, char* buffer, int bufSize) {
  byte ch; // byte read from eeprom
  int bytesRead; // number of bytes read so far
  if (!eeprom_is_addr_ok(addr)) { // check start address
    return false;
  }

  if (bufSize == 0) { // how can we store bytes in an empty buffer ?
    return false;
  }
  // is there is room for the string terminator only, no reason to go further
  if (bufSize == 1) {
    buffer[0] = 0;
    return true;
  }
  bytesRead = 0; // initialize byte counter
  ch = EEPROM.read(addr + bytesRead); // read next byte from eeprom
  buffer[bytesRead] = ch; // store it into the user buffer
  bytesRead++; // increment byte counter
  // stop conditions:
  // - the character just read is the string terminator one (0x00)
  // - we have filled the user buffer
  // - we have reached the last eeprom address
  while ( (ch != 0x00) && (bytesRead < bufSize) && ((addr + bytesRead) <= EEPROM_MAX_ADDR) ) {
    // if no stop condition is met, read the next byte from eeprom
    ch = EEPROM.read(addr + bytesRead);
    buffer[bytesRead] = ch; // store it into the user buffer
    bytesRead++; // increment byte counter
  }
  // make sure the user buffer has a string terminator, (0x00) as its last byte
  if ((ch != 0x00) && (bytesRead >= 1)) {
    buffer[bytesRead - 1] = 0;
  }
  return true;
}

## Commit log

2018-04-22 Initial Commit
    - Added source files for the following modules: Detection Unit, Base Station, and Web Server
    [Fritzing- Programming.fzz, Fritzing-Bootloading.fzz, STEM.brd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]
2018-04-22 Re-structured repository
    [Fritzing- Programming.fzz, Fritzing-Bootloading.fzz, STEM.brd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]
2018-04-22 Added Power Subsystem schematic

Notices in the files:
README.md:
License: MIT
